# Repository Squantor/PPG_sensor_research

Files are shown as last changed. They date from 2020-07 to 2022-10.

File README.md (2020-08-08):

# PPG sensor research
This repository contains electronics, mechanical, embedded and PC side software into researching how PPG sensors work. 
## Structure
* [Electronics](https://github.com/Squantor/PPG_sensor_research/tree/master/electronics) contains the various iterations of PPG sensors
* [Software](https://github.com/Squantor/PPG_sensor_research/tree/master/software) contains the software needed for the project, either embedded or PC side software
* Scripts contain data analysis software
* Mechanical contains drawings of casing/mechanisms etc
## Checking out
This project makes extensive use of submodules, use ```git clone --recurse-submodules https://github.com/Squantor/PPG_sensor_research.git``` to clone the repository and its submodules in one go.
# Disclaimer
This project does not comprise a medical device and is not intended as such. USE AT YOUR OWN RISK!

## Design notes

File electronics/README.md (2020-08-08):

# PPG sensor electronics
Here are a bunch of hardware prototypes to explore how to make a working PPG sensor.
## Electronic versions
* [Sensor version V1.0](https://github.com/Squantor/PPG_sensor_research/tree/master/electronics/Sensor_V1.0) is the first hardware iteration, this is to create a final hardware layout for the sensor and measure it.
* Sensor version V2.0 contains everything from 1.0 but with all the unneeded research components stripped. Additionally: USB to serial converter, Serial flash for datastorage, accelerometer for data storage and battery charger controller.
* Sensor version V3.0 contains everything from 2.0 but now in a portable form factor.

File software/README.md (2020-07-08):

# PPG sensor software
This is the software root, building is done from here.
## Projects
See per project for more details:
* [PPG sensor V000](https://github.com/Squantor/PPG_sensor_research/tree/master/software/PPG_sensor_V000) test software
## Checking out
use ```git clone --recurse-submodules https://github.com/Squantor/$(PROJECT).git``` to clone the repository and its submodules.
## Compiling
There are multiple projects present in this directory. Invoking compilation of any project is done with the ```PROJECT``` variable that needs to be passed on, see the following example:
```
make PROJECT=LPC812_uart_example
```
Building can be done with various configurations that set up flags and other settings, this configuration is set with the ```CONFIG``` variable. Most projects have the ```release``` and ```debug``` where the ```debug``` configuration is default.
The ```release``` configuration has optimizations enabled (usually for size) and minimal included debugging information. The ```debug``` configuration has NO optimization and full debugging information. There might be specific configurations available per project.  When no ```CONFIG``` is defined the default is the ```debug``` configuration.
### Embedded targets
For debugging on embedded targets, the [Black Magic Probe](https://github.com/blacksphere/blackmagic/wiki) is used, scripts to use this debugger are present in the ```gdb_scripts``` directory. make can be used to invoke debugging:
```
make PROJECT=LPC812_uart_example gdbusbdebug
make PROJECT=LPC812_uart_example gdbusbrelease
```
This will build, if needed, the debug or release build respectivly and load it into the target.
```
make PROJECT=LPC812_uart_example tpwrdisable
make PROJECT=LPC812_uart_example tpwrenable
```
The black magic probe is capable of powering the target, these commands enable/disable this function.
### Depedencies
The projects have a few dependencies:
* [LibMcuLl](https://github.com/Squantor/libMcuLL) for the chip specific routines
* [squantorLibC](https://github.com/Squantor/squantorLibC) contains a minimal LibC implementation
* [squantorLibEmbeddedC](https://github.com/Squantor/squantorLibEmbeddedC) contains various routines useful in embedded systems
* squantorLibEmbeddedCpp

Do not forget to clone with ```--recurse-submodules```.
## Usage
You will need the following hardware to try out these projects:
* [Black magic probe](https://github.com/blacksphere/blackmagic) or any other SWD capable programmer
* [Homebrew development boards](https://github.com/Squantor/squantorDevelBoards)
* [LPC breakout boards](https://github.com/Squantor/LPC-breakout-boards)

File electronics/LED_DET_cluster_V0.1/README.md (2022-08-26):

# Prototyping 4 LED PPG sensor cluster
Simple breakout for the 4 led PPG sensor cluster. Contains footprints for 6 leds, but a maximum of 4 can be populated, or 6 if you get creative? Just to try out various LED/sensor configurations.
## TODO's
Still some things need to be done:
* Review with one night in between
* Produce at [OSHPARK](https://oshpark.com/)
* Assemble
* Test & characterise
* update Readme.md with pictures and BOM
## BOM
* Flexible LED footprint, from 0603 LED to OSRAM PointLED (top mount)
* Flexible detector footprint, from 0603 Phototransistor to OSRAM SHF2440

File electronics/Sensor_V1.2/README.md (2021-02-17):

# PPG sensor hardware Version 1.2
After the lessons learned from version 1.2 it is time to simplify the hardware and explore more sensor combinations
* Try again the internal comparator but do not reserve space for this
* LPC pins broken out
* Go fully for the ADC concept, maybe via wires go to the internal comparator
* Make use of the smaller LPC824HI33 nuclone
* investigate a top only sensor without PCB cutouts with 3d printed spacers
* remove most of the superfluous hardware
# HSI (Hardware Software Interface)
What microcontroller pins are connected to what hardware and what are the needed settings
* PIO0_13 is connected to anode of LED1, should be set as output. Low turns on the LED1
* PIO0_12 is connected to anode of LED1, should be set as output. Low turns on the LED2
* PIO0_4 is connected to the gate of a transistor that resets the integrator capacitor, pulled down by a 10K resistor, should be set as output
* PIO0_25 is connected to UART receive via 100Ohm series resistor, should be set as output
* PIO0_24 is connected to UART transmit via a 100Ohm series resistor, should be set as input
* PIO0_18 is connected to the Photodiode integrator node via a normally open jumper, should be set as analog input
## TODO's
Still some things need to be done:
* Sign off to production
* Assembly
* Test & characterise, make a separate document in the documentation directory
* update Readme.md with pictures and BOM
## BOM
This design is made so flexible it accepts many different light detecting elements and LED's, some sensors/LED's tried out are are:
* [SFH2440](https://www.osram.com/ecat/DIL%20SMT%20Ambient%20Light%20Sensor%20SFH%202440/com/en/class_pim_web_catalog_103489/global/prd_pim_device_2219615/) Photodiode
* [SFH3710](https://lcsc.com/product-detail/Sensors_OSRAM_SFH3710-Z_SFH-3710-Z_C129152.html) Phototransistor
* [NCD0805G1](https://lcsc.com/product-detail/Light-Emitting-Diodes-LED_Emerald-SMDLED-Iv-220-270mcd-atIF-5mA_C84260.html) 525nm LED
* [SIR15-21C/TR8 ](https://lcsc.com/product-detail/Others_Everlight-Elec-SIR15-21C-TR8_C264405.html) 875nm IR LED
## Pictures

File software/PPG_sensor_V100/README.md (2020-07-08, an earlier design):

# PPG sensor with V000 hardware
This project runs on the V000 proto hardware.
# HSI
Hardware Software Interface
* GPIO17 set as input and connected to UART TX of the USB to serial converter
* GPIO13 set as output and connected to UART RX of the USB to serial converter
* GPIO12 set as output and connected to the PPG sensor LED's
# TODO
* Expand this document a good deal more
* Add pictures

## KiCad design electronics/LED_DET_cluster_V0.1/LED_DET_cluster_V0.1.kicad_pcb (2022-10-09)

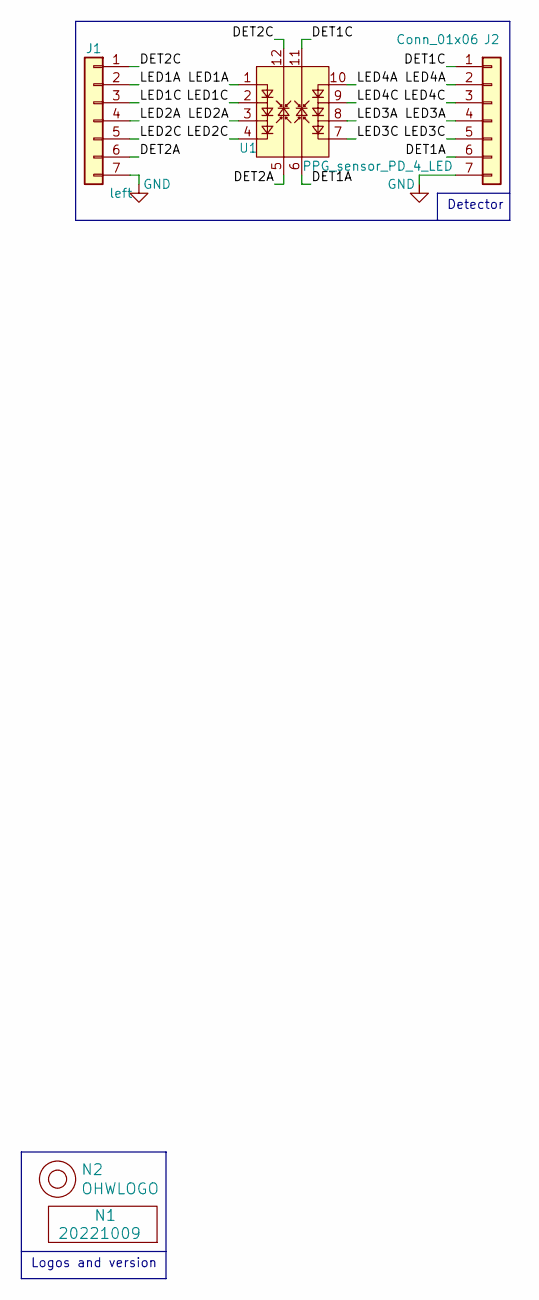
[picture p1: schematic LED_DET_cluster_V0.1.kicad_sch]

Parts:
J1: left; Header-0254-1X07-H010
J2: Conn_01x06; Header-0254-1X07-H010
N1: 20221009; Label_Generic
N2: OHWLOGO; OSHW-Symbol_6.7x6mm_SilkScreen
U1: PPG_sensor_PD_4_LED; PPG_sensor_4LED

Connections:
/DET1A: J2.6, U1.6
/DET1C: J2.1, U1.11
/DET2A: J1.6, U1.5
/DET2C: J1.1, U1.12
/LED1A: J1.2, U1.1
/LED1C: J1.3, U1.2
/LED2A: J1.4, U1.3
/LED2C: J1.5, U1.4
/LED3A: J2.4, U1.8
/LED3C: J2.5, U1.7
/LED4A: J2.2, U1.10
/LED4C: J2.3, U1.9
GND: J1.7, J2.7

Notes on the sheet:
Detector
Logos and version

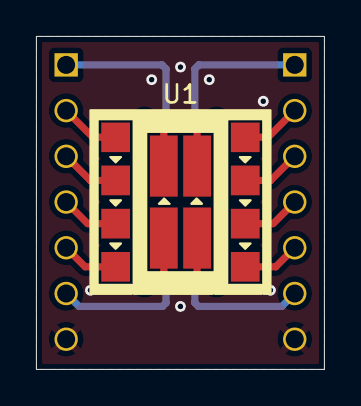
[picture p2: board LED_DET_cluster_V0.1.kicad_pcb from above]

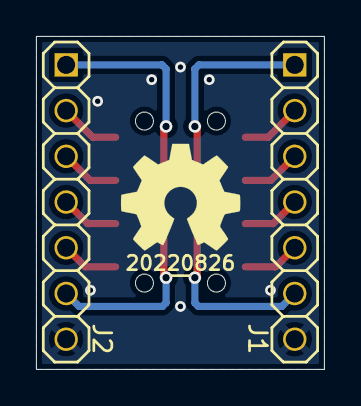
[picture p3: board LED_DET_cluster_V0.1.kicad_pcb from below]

Board: 2 copper layers, 16.0 x 18.5 mm, 5 parts (4 on the bottom side), 13 nets.

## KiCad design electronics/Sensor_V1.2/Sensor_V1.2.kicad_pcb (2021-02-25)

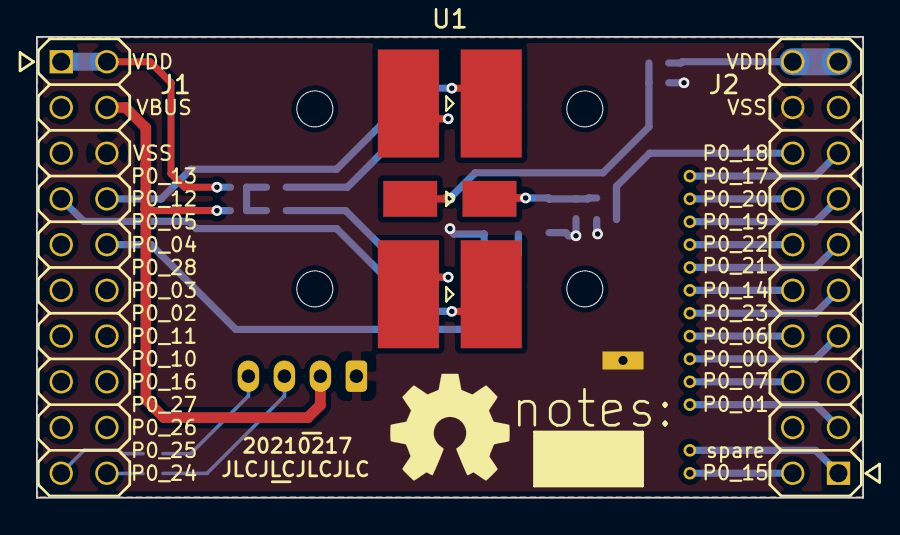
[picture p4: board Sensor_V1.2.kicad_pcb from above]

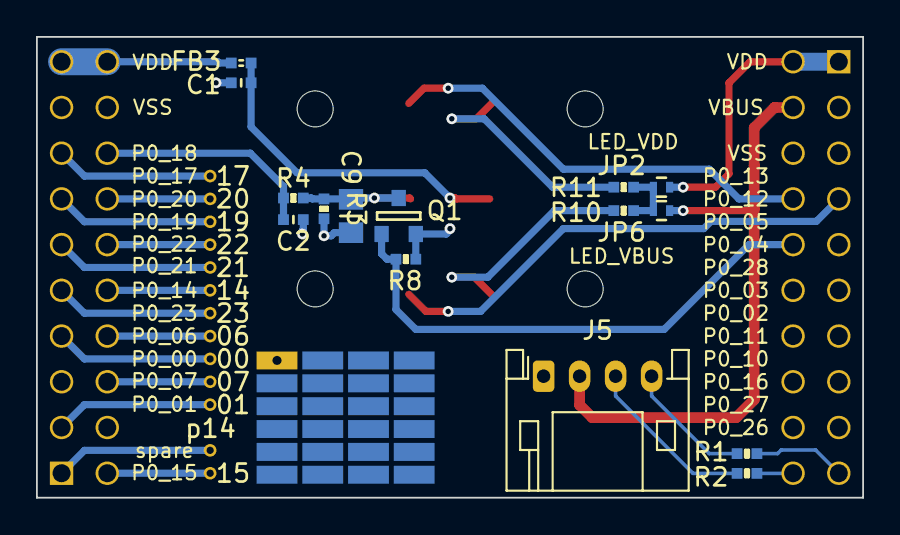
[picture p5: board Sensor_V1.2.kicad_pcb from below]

Board: 2 copper layers, 45.9 x 25.6 mm, 36 parts (29 on the bottom side), 30 nets.

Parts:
C1: 1u; C_0402
C2: TBD; C_0402
C9: 4n7; C_0805+0603
FB3: Ferrite_Bead; L_0402
J1: nuclone_small_left
J2: nuclone_small_right
J3: Proto_1pin; proto-SMD-0127-08X06-P010X020+pin
J5: DevBoardUartInput; JST_PH_S4B-PH-K_1x04_P2.00mm_Horizontal
JP2: LED_VDD; solder_jumper_2way_noconn
JP6: LED_VBUS; solder_jumper_2way_noconn
N1: OHWLOGO; OSHW-Symbol_6.7x6mm_SilkScreen
N2: 20210217; Label_Generic
N3: JLCJLCJLCJLC; Label_Generic
N4: notes:; Label_Note_medium
Q1: DMG1012; SOT23-3
R1, R2: 100; R_0402_hand
R3, R4: TBD; R_0402_hand
R8: 4.7K; R_0402_hand
R10, R11: 1K; R_0402_hand
TP1: 20; TestPoint_hole_H04R07
TP2: 22; TestPoint_hole_H04R07
TP3: 14; TestPoint_hole_H04R07
TP4: 06; TestPoint_hole_H04R07
TP5: 07; TestPoint_hole_H04R07
TP6: 15; TestPoint_hole_H04R07
TP7: 17; TestPoint_hole_H04R07
TP8: 19; TestPoint_hole_H04R07
TP9: 21; TestPoint_hole_H04R07
TP10: 23; TestPoint_hole_H04R07
TP11: 00; TestPoint_hole_H04R07
TP12: 01; TestPoint_hole_H04R07
TP13: p14; TestPoint_hole_H04R07
U1: PPG_sensor; PPG_sensor_front_universal

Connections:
/GPIO_14: J2.1, TP13.1
/I_reset: J1.10, Q1.1, R8.2
/LED1_A: R10.2, U1.1
/LED1_C: J1.7, U1.6
/LED2_A: R11.2, U1.3
/LED2_C: J1.8, U1.4
/LED_VDD: JP2.1, JP6.1, R10.1, R11.1
/P0_00: J2.7, TP11.1
/P0_01: J2.3, TP12.1
/P0_06: J2.8, TP4.1
/P0_07: J2.6, TP5.1
/P0_14: J2.10, TP3.1
/P0_15: J2.2, TP6.1
/P0_17: J2.15, TP7.1
/P0_19: J2.13, TP8.1
/P0_20: J2.14, TP1.1
/P0_21: J2.11, TP9.1
/P0_22: J2.12, TP2.1
/P0_23: J2.9, TP10.1
/PD_ADC: C2.2, J2.16, R4.1
/PD_BIAS: C1.2, FB3.2, U1.2
/PD_OUT: C9.1, Q1.3, R3.1, R4.2, U1.5
/UART_RX: J1.19, R1.1
/UART_TX: J1.20, R2.1
/VBUS: J1.4, J5.2, JP6.2
/VDD: J1.1, J1.2, JP2.2
/VDDA: FB3.1, J2.19, J2.20
/VSS: C1.1, C2.1, C9.2, J1.6, J2.18, J3.1, J5.1, Q1.2, R3.2, R8.1
unnamed: J5.3, R2.2
unnamed: J5.4, R1.2

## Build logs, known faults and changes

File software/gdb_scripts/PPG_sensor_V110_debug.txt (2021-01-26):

file bin/PPG_sensor_V110/debug/PPG_sensor_V110.elf
target extended-remote /dev/ttyACM0
shell sleep 1
monitor swdp_scan
attach 1
set mem inaccessible-by-default off
set {int}0x40048000 = 2
load bin/PPG_sensor_V110/debug/PPG_sensor_V110.elf
set {int}0x40048000 = 2
compare-sections
b main

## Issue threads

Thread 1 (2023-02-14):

Parameters

Furki81, 2023-02-14:
Hi,,
i'm try to understand the code.
in the PPG_sensor _V000 section, main.cpp file line 57
where this SYSCTL_CLOCK_SWM parameter defined ??
Can you say that?

Furki81, 2023-02-14:
@Squantor

Squantor, 2023-02-14:
@Furki81 This is defined in PPG_sensor_research/software/libMcuLL/inc/nxp/LPC8XX/LPC8XX_clock.h and is used to enable/disable clocking to the SWM. The library libMcuLL is my own hal library for the microcontrollers I use but this code base is a bit old and the libraries are a bit old too. I am planning to revisit this code and use the RP2040 instead of the LPC microcontroller so people can reproduce this.

I really suggest you install visual studio code so you can browse through the code and see where everything is defined.

Furki81, 2023-02-14:
Thanks for your reply. But i could not find visual studio code. Can you help me to find ?

Squantor, 2023-02-14:
You can download [https://code.visualstudio.com/](visual studio code) from here.

What do you want to do with this code? PPG sensor V000 hardware is not really documented, I suggest you find some other project for PPG sensors.

Furki81, 2023-02-14:
I understand that it is not documented. I only try to understand how you builded a PPG sensor project with c/c++ language.

Squantor, 2023-02-14:
Good, just want to manage your expectations. V000 is very primitive and just uses a scheme of turning LED on and waiting until the comparator switches. The time between LED on and comparator switch is measured and used as the value for reflectivity. V120 of the software does it a bit more "normal" by turning the LED on for a period, and measuring the integration capacitor value.

If it is very low it will increase the LED on time, if it is very high it will decrease LED on time. This will keep the PPG signal in the middle of the ADC range, this way you have the most signal.

This worked pretty well but I had a bit more problems with noise, that made it hard to detect the signal. I want to revisit this project for a while but other things are getting in the way.

Furki81, 2023-02-15:
Thanks a lot for your help. Can I ask questions in here while i 'm building PPG sensor with Stm32 MCU application? I will be pleased if you navigate me to complete my project for sure in your suitable time.

Squantor, 2023-02-15:
I have only experience in getting raw reflectivity data from a homebrew PPG sensor. I think there are better libraries/projects that do things like extracting heart rate from such data to base your project on. Feel free to ask, but my knowledge is limited.

Furki81, 2023-02-15:
Thanks, a lot.

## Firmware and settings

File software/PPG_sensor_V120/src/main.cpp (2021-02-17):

/*
 * SPDX-License-Identifier: MIT
 *
 * Copyright (c) 2021 Bart Bilos
 * For conditions of distribution and use, see LICENSE file
 */
/*
 * PPG sensor demo program, now just initializes the SCT and times the
 * time until the comparator flips.
 */
#include <board.hpp>
#include <mcu_ll.h>
#include <stream_uart.hpp>
#include <print.h>
#include <time_delay.hpp>
#include <time_interval.hpp>
#include <PPG_sensor_adc.hpp>
#include <moving_average.hpp>

util::MovingAverage<uint16_t, 10> ledScaleInput(PPG_SENSOR_ADC_MID);

int main()
{
    uint16_t currentSample;
    uint32_t ledOnTime = PPG_SENSOR_LED_DEFAULT;

    boardInit();
    ppgSensorSetup();
    dsPuts(&streamUart, "PPG sensor V1.2 development program\n");
    while (1) 
    {
        __NOP();
        if(ppgSensorSamplePresent(currentSample))
        {
            ledScaleInput.add(currentSample);
            if( ledScaleInput.get() > PPG_SENSOR_ADC_HIGH && 
                ledOnTime > PPG_SENSOR_LED_MIN )
            {
                ledScaleInput.reset(PPG_SENSOR_ADC_MID);
                ledOnTime -= PPG_SENSOR_LED_STEP;
                ppgSetLedOnTime(ledOnTime);
            }
            else if(ledScaleInput.get() < PPG_SENSOR_ADC_LOW &&
                    ledOnTime < PPG_SENSOR_LED_MAX )
            {
                ledScaleInput.reset(PPG_SENSOR_ADC_MID);
                ledOnTime += PPG_SENSOR_LED_STEP;
                ppgSetLedOnTime(ledOnTime);
            }
            dsPuts(&streamUart, "/*");
            printDecNzU16(&streamUart, currentSample);
            dsPuts(&streamUart, ",");
            printDecNzU16(&streamUart, ledScaleInput.get());
            dsPuts(&streamUart, ",");
            printDecNzU32(&streamUart, ledOnTime);
            dsPuts(&streamUart, "*/\n");
        }
    }
}

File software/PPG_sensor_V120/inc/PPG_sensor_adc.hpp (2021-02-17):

/*
 * SPDX-License-Identifier: MIT
 *
 * Copyright (c) 2021 Bart Bilos
 * For conditions of distribution and use, see LICENSE file
 */
#ifndef PPG_SENSOR_ADC_HPP
#define PPG_SENSOR_ADC_HPP

#include <stdint.h>

#define PPG_SENSOR_FREQ         (1000000)

#define PPG_SENSOR_IRESET       (1000)
#define PPG_ADC_RATE            (1000000u)

#define PPG_SENSOR_LED_MAX      (500000)
#define PPG_SENSOR_LED_DEFAULT  (100000)
#define PPG_SENSOR_LED_MIN      (20000)

#define PPG_SENSOR_LED_STEP     (20000)

#define PPG_SENSOR_ADC_LOW  (1024u)
#define PPG_SENSOR_ADC_HIGH (3072u)
#define PPG_SENSOR_ADC_MID  (2048u)

void ppgSensorSetup(void);

bool ppgSensorSamplePresent(uint16_t &sample);

void ppgSetLedOnTime(uint32_t value);

#endif

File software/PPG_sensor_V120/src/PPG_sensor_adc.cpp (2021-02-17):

/*
 * SPDX-License-Identifier: MIT
 *
 * Copyright (c) 2021 Bart Bilos
 * For conditions of distribution and use, see LICENSE file
 */
#include <board.hpp>
#include <mcu_ll.h>
#include <PPG_sensor_adc.hpp>
#include <ringbuf.hpp>
#include <moving_average.hpp>

util::RingBuffer<uint16_t, 15> ppgBuf;

extern "C" {
    void ADC_SEQA_IRQHandler(void)
    {
        uint32_t adcResult = AdcGetDataReg(LPC_ADC, ADC_CAP_SENSE);
        if(adcResult & ADC_DR_DATAVALID)
        {
            uint16_t sample = ADC_DR_RESULT(adcResult);
            ppgBuf.pushFront(sample);
        }
        AdcClearFlags(LPC_ADC, AdcGetFlags(LPC_ADC));
    }
}

/**
 * @brief   Sets up the needed peripherals PPG sensing
 * @note    The SCT is used for the comparator based PPG sensor, iocon and pin muxing should
 * be setup beforehand.
 */
void ppgSensorSetup(void)
{  
    ppgBuf.reset();

    
    SctInit(LPC_SCT);
    // setup ADC clock division in preparation for ADC calibration
    AdcInit(LPC_ADC, ADC_CR_CLKDIV(CLOCK_AHB / ADC_CAL_CLOCK));
    AdcStartCalibration(LPC_ADC);
    while(AdcIsCalibrationDone(LPC_ADC) == false)
        ;
    AdcSetDivider(LPC_ADC, CLOCK_AHB / PPG_ADC_RATE);

    // setup ADC
    AdcSetupSequencer(LPC_ADC, ADC_SEQA_IDX, 
        ADC_SEQ_CTRL_CHANSEL(ADC_CAP_SENSE) | 
        ADC_SEQ_CTRL_HWTRIG_PINTRIG0 | 
        ADC_SEQ_CTRL_HWTRIG_POLPOS |
        ADC_SEQ_CTRL_MODE_EOS );

    ClockEnablePeriphClock(SYSCTL_CLOCK_SWM);
    SwmFixedPinEnable(SWM_CAP_SENSE, true);
    SwmMovablePinAssign(SWM_ADC_PINTRIG0_I, PIN_LED1_CTRL);
    ClockDisablePeriphClock(SYSCTL_CLOCK_SWM);

    SctSetConfig(LPC_SCT, SCT_CONFIG_32BIT_COUNTER | SCT_CONFIG_AUTOLIMIT_U);

    inmuxSetSCTInMux(LPC_INMUX, SCT_INMUX_0, SCT_INP_IN0);

    SctMatchU(LPC_SCT, SCT_MATCH_0, PPG_SENSOR_FREQ);
    SctMatchReloadU(LPC_SCT, SCT_MATCH_0, PPG_SENSOR_FREQ);
    SctMatchU(LPC_SCT, SCT_MATCH_1, PPG_SENSOR_FREQ-PPG_SENSOR_IRESET);
    SctMatchReloadU(LPC_SCT, SCT_MATCH_1, PPG_SENSOR_FREQ-PPG_SENSOR_IRESET);
    SctMatchU(LPC_SCT, SCT_MATCH_2, PPG_SENSOR_LED_DEFAULT);
    SctMatchReloadU(LPC_SCT, SCT_MATCH_2, PPG_SENSOR_LED_DEFAULT);

    // Event 0 determines the sampling frequency
    SctSetEventStateMask(LPC_SCT, SCT_EVENT_0_VAL, SCT_STATE_0_BIT | SCT_STATE_1_BIT);
    SctSetEventControl(LPC_SCT, SCT_EVENT_0_VAL, SCT_EV_CTRL_MATCHSEL(SCT_MATCH_0) | SCT_EV_CTRL_COMBMODE(SCT_COMBMODE_MATCH));
    // Event 1 triggers the integrator capacitor reset
    SctSetEventStateMask(LPC_SCT, SCT_EVENT_1_VAL, SCT_STATE_0_BIT | SCT_STATE_1_BIT);
    SctSetEventControl(LPC_SCT, SCT_EVENT_1_VAL, SCT_EV_CTRL_MATCHSEL(SCT_MATCH_1) | SCT_EV_CTRL_COMBMODE(SCT_COMBMODE_MATCH));
    // Event 3 turns the LED off and triggers a ADC sample
    SctSetEventStateMask(LPC_SCT, SCT_EVENT_3_VAL, SCT_STATE_0_BIT | SCT_STATE_1_BIT);
    SctSetEventControl(LPC_SCT, SCT_EVENT_3_VAL, SCT_EV_CTRL_MATCHSEL(SCT_MATCH_2) | SCT_EV_CTRL_COMBMODE(SCT_COMBMODE_MATCH));
    SctRegisterModeU(LPC_SCT, 
        SCT_REGMODE_U(SCT_MATCH_0, SCT_REGMODE_MATCH) | 
        SCT_REGMODE_U(SCT_MATCH_1, SCT_REGMODE_MATCH) | 
        SCT_REGMODE_U(SCT_MATCH_2, SCT_REGMODE_MATCH) );
    
    // LED1 control
    SctOutputSet(LPC_SCT, SCT_OUTPUT_0_VALUE, SCT_EVENT_1_BIT | SCT_EVENT_3_BIT); // disable led at end
    SctOutputClear(LPC_SCT, SCT_OUTPUT_0_VALUE, SCT_EVENT_0_BIT); // enable LED at start
    // LED 2 control
    SctOutputSet(LPC_SCT, SCT_OUTPUT_1_VALUE, SCT_EVENT_1_BIT | SCT_EVENT_3_BIT); // disable led at end
    SctOutputClear(LPC_SCT, SCT_OUTPUT_1_VALUE, SCT_EVENT_0_BIT); // enable LED at start
    // integrator reset control
    SctOutputSet(LPC_SCT, SCT_OUTPUT_2_VALUE, SCT_EVENT_1_BIT);
    SctOutputClear(LPC_SCT, SCT_OUTPUT_2_VALUE, SCT_EVENT_0_BIT);
    // setup outputs to initial values
    SctOutput(LPC_SCT,  
        SCT_OUTPUT_STATE(SCT_OUTPUT_0_VALUE, 0) |
        SCT_OUTPUT_STATE(SCT_OUTPUT_1_VALUE, 0) | 
        SCT_OUTPUT_STATE(SCT_OUTPUT_2_VALUE, 0) );

    AdcEnableInt(LPC_ADC, ADC_INTEN_SEQA_ENABLE);
    NVIC_EnableIRQ(ADC_SEQA_IRQn);
    AdcEnableSequencer(LPC_ADC, ADC_SEQA_IDX);
    SctClearControl(LPC_SCT, SCT_CTRL_HALT_U);
}

/**
 * @brief   Checks if a new PPG sample is present and returns it
 * @param   sample  : reference to a sample buffer
 * @return  true if a new sample has been returned
 * @note    
 */
bool ppgSensorSamplePresent(uint16_t &sample)
{
    return ppgBuf.popBack(sample);
}

/**
 * @brief   Sets the PPG sensor LED on time
 * @param   value   : new on time in clock ticks
 * @return  none
 * @note    
 */

void ppgSetLedOnTime(uint32_t value)
{
    SctSetControl(LPC_SCT, SCT_CTRL_HALT_U);
    SctMatchReloadU(LPC_SCT, SCT_MATCH_2, value);
    SctClearControl(LPC_SCT, SCT_CTRL_HALT_U);
}

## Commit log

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2020-08-02 added capacitor reset output
    [PPG_sensor_V000.hpp, main.cpp]
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2020-08-03 disabled pullup on cap sensing pin, initialised comparator input, preparation for integrator reset transistor
    [main.cpp]
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2020-08-03 added integrator reset output
    [main.cpp]
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2020-08-04 fixed error in setup
    [main.cpp]
2020-08-04 added printing of sensor values, but there is some noise, time for a proper proto?
    [main.cpp]
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2020-08-07 switched to external divider instead of internal one, much lower noise
    [main.cpp]
2020-08-08 added sensor electronics version V1.0
    [Sensor_V1.0.kicad_pcb, Sensor_V1.0.sch]
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2020-08-09 added LED drive connections, started with PPG sensor connections
    [Sensor_V1.0.sch]
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2020-08-09 done with PPG sensor nodes, working on PD bias supply selection
    [Sensor_V1.0.sch]
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2020-08-09 updated with new PPG footprint
    [Sensor_V1.0.sch]
2020-08-09 WIP some layout and additional testpoints
    [Sensor_V1.0.kicad_pcb, Sensor_V1.0.sch]
2020-08-09 WIP more layout and extra testpoints added, next step are my own testpoints, those from kicad are just annoying
    [Sensor_V1.0.kicad_pcb, Sensor_V1.0.sch]
2020-08-09 updated testpoints to something smaller
    [Sensor_V1.0.kicad_pcb, Sensor_V1.0.sch]
2020-08-09 WIP some placement and component changes
    [Sensor_V1.0.kicad_pcb, Sensor_V1.0.sch]
2020-08-09 changed some testpads, some futher placement
    [Sensor_V1.0.kicad_pcb, Sensor_V1.0.sch]
2020-08-09 added integrator capacitor and reset, WIP resistor divider
    [Sensor_V1.0.sch]
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2020-08-09 some placement optimizations and minor routing
    [Sensor_V1.0.kicad_pcb]
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2020-08-09 forgot to commit some component definitions
    [Sensor_V1.0.sch]
2020-08-09 updated pcb library, added comparator bits, some placement and debugging ERC errors
    [Sensor_V1.0.sch]
2020-08-09 fixed ERC errors
    [Sensor_V1.0.sch]
2020-08-09 WIP comparator section and final fixes for ERC
    [Sensor_V1.0.kicad_pcb, Sensor_V1.0.sch]
2020-08-10 updated versionnumber, added decoupling capacitor on resistor network
    [Sensor_V1.0.sch]
2020-08-10 added resistor network decoupling capacitpr
    [Sensor_V1.0.kicad_pcb]
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2020-08-10 updated some more placement
    [Sensor_V1.0.kicad_pcb]
2020-08-11 simplified resistor divider, I have E24 range at home, no need to mess with series/parallel combinations
    [Sensor_V1.0.sch]
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2020-08-11 added mask opening for guard trace
    [Sensor_V1.0.kicad_pcb]
2020-08-11 beautified position a bit (ordering of capacitor to be incrementing
    [Sensor_V1.0.kicad_pcb]
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2020-08-12 added 3d models to a few components
    [Sensor_V1.0.kicad_pcb]
2020-08-12 minor changes, reverted default line thickness
    [Sensor_V1.0.kicad_pcb]
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2020-08-12 moved test points a bit out of the way of the sensor
    [Sensor_V1.0.kicad_pcb]
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2020-08-21 moved integrator reset to SCT output 2
    [main.cpp]
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2020-08-23 trying some fixes for lost capture problem
    [PPG_sensor_V100.hpp]
2020-08-24 noise debugging of PPG sensor
    [main.cpp]
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2020-08-25 increased sampling rate and reduced the integrator reset period after changing base drive resistor
    [main.cpp]
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2020-09-08 copied Version 1.0 to version 1.1 hardware
    [Sensor_V1.1.kicad_pcb, Sensor_V1.1.sch]
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2020-09-08 started with schematic modifications
    [Sensor_V1.1.sch]
2020-09-08 minor layout changes and component swaps
    [Sensor_V1.1.kicad_pcb, Sensor_V1.1.sch]
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2020-09-18 placement and some routing of led drive circuitry
    [Sensor_V1.1.kicad_pcb]
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2020-09-18 initial placement of some components
    [Sensor_V1.1.kicad_pcb]
2020-10-01 schematic modifications and cleanup
    [Sensor_V1.1.sch]
2020-10-01 easier routing of UART pins
    [Sensor_V1.1.kicad_pcb, Sensor_V1.1.sch]
2020-10-01 updated layout and started with starground/VDDA
    [Sensor_V1.1.kicad_pcb, Sensor_V1.1.sch]
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2020-10-18 added PD net ties, more ties needed
    [Sensor_V1.1.kicad_pcb, Sensor_V1.1.sch]
2020-10-18 net ties for comparator
    [Sensor_V1.1.sch]
2020-10-18 starting to move analog stuff to VSSA and then to star grounds/vcc's. imported net ties
    [Sensor_V1.1.kicad_pcb, Sensor_V1.1.sch]
2020-10-31 undoing most of the net splitting for a star VSS/VDD
    [Sensor_V1.1.sch]
2020-10-31 added ADC sampling connection
    [Sensor_V1.1.sch]
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2020-10-31 added some ferrite beads
    [Sensor_V1.1.sch]
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2020-10-31 added all noconnects, fixed ERC errors
    [Sensor_V1.1.sch]
2020-11-06 added PD bias decoupling and ferrite bead
    [Sensor_V1.1.sch]
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2020-12-11 adapted LED drive circuit
    [Sensor_V1.1.sch]
2020-12-11 fixed DRC errors
    [Sensor_V1.1.sch]
2020-12-11 fixed a small mistake with decoupling and ferrites
    [Sensor_V1.1.sch]
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2020-12-13 changed the led drive shunt to be ground referenced
    [Sensor_V1.1.sch]
2020-12-13 updated schematic into PCB
    [Sensor_V1.1.kicad_pcb]
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2020-12-13 changed integrator capacitor size to something smaller
    [Sensor_V1.1.sch]
2020-12-13 again updated integrator capacitor footprint
    [Sensor_V1.1.sch]
2020-12-13 placed more parts on the integrator/comparator side
    [Sensor_V1.1.kicad_pcb]
2020-12-13 placed resistor divider and voltage reference
    [Sensor_V1.1.kicad_pcb]
2020-12-13 fixed DRC issues
    [Sensor_V1.1.kicad_pcb]
2020-12-13 further silk screen placement of the reference, bias arrangement and photodiode integrator
    [Sensor_V1.1.kicad_pcb]
2020-12-13 removed some pin labels that overlapped too much
    [Sensor_V1.1.kicad_pcb]
2020-12-13 wrong header placement
    [Sensor_V1.1.kicad_pcb]
2020-12-13 schanged UART RX/TX pinning due to flipped connector
    [Sensor_V1.1.sch]
2020-12-13 renaming labels, fixxing some routing
    [Sensor_V1.1.kicad_pcb]
2020-12-13 fixed labels on the left side
    [Sensor_V1.1.kicad_pcb]
2020-12-13 fixed labels on right hand connector
    [Sensor_V1.1.kicad_pcb]
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2020-12-15 silk changes, component placement changed, replaced PD ADC connection with a jumper
    [Sensor_V1.1.kicad_pcb, Sensor_V1.1.sch]
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2021-01-28 fixed crystaloscillator issue, tried to get the SCT going but does not work, yet
    [main.cpp]
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2021-02-12 added bugfixed moving average filter C variant
2021-02-12 added ringbuffer sample caching and moving average filter for noise filtering
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2021-02-13 fixed build error switching from comparator PPG to ADC PPG
    [main.cpp]
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2021-02-13 made LED turn ond and off at a fixed blink rate
    [PPG_sensor_adc.cpp, PPG_sensor_adc.hpp]
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2021-02-14 copied over V1.1 to V1.2 sensor
    [Sensor_V1.2.kicad_pcb, Sensor_V1.2.sch]
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2021-02-14 passing ERC, added test pad section, added RC to ADC input
    [Sensor_V1.2.sch]
2021-02-14 imported some changed components, but need to redo the footprints from TODO
    [Sensor_V1.2.kicad_pcb]
2021-02-15 finished schematic and passes ERC
    [Sensor_V1.2.sch]
2021-02-15 initial placement of components
    [Sensor_V1.2.kicad_pcb]
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2021-02-15 updated versionnumber, added prototyping area, changed connectors
    [Sensor_V1.2.sch]
2021-02-15 not enough space for prototyping area
    [Sensor_V1.2.sch]
2021-02-15 components placed, changing silk
    [Sensor_V1.2.kicad_pcb]
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2021-02-15 changed header labels, changed test point labels
    [Sensor_V1.2.kicad_pcb]
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2021-02-16 completed PCB silk placement
    [Sensor_V1.2.kicad_pcb]
2021-02-17 added notes field, updated versionnumber
    [Sensor_V1.2.kicad_pcb, Sensor_V1.2.sch]
2021-02-17 added some additional channels, increased baud rate for serial studio, integrated moving average with settable reset average
    [PPG_sensor_adc.cpp, PPG_sensor_adc.hpp, main.cpp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]
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2022-08-26 started with PPG detector cluster project
    [LED_DET_cluster_V0.1.kicad_pcb, LED_DET_cluster_V0.1.kicad_sch]
2022-08-26 completed LED detector cluster 0.1
    [LED_DET_cluster_V0.1.kicad_pcb, LED_DET_cluster_V0.1.kicad_sch]
2022-08-27 updating sensor cluster breakout
    [LED_DET_cluster_V0.1.kicad_pcb]
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
